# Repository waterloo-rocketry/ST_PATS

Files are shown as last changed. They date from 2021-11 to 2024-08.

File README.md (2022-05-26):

# ST PATS
Stpats is a system that tracks the location of the rocket and tells us where
and which direction to go to find it.

There are two modes of operation: serial and radio. In serial mode, GPS
coordinate is received from USB serial; in radio mode, GPS coordinate is
received from the radio module.

## Calibration
The on-board compass needs to be calibrated when a firmware is flashed or when
using stpats in a new environment. The compass will not work correctly without
calibration. To enter calibration mode, press the left button. The min/max
value of each axis should appear on the top left of the screen. Rotate the
whole device in every direction so the numbers stabilize, the press the left
button again to save the calibration.

## Radio Telemetry
The radio and serial mode can be toggled using the right button. At the time of
writing, the live telemetry is not done yet, so I used an Arduino to send fake
coordinates at 57600 baud to test serial reading and parsing. In theory,
plugging in configured live telemetry breakout should just work. In reality,
who knows.

## Serial Telemetry
As an alternative to radio telemetry, USB serial can also be used to send GPS
coordinate to stpats. The serial mode can be switched to using the right
button. The GPS message has the format of `[0-9]+.[0-9]*[NSEWM]`, for example:
`12.34N56.78W90M` means 12.34 degrees north, 56.78 degrees west, 90m high. The
altitude information is not used in the calculations so it’s optional.

## aprs2stpats.py
`utils/aprs2stpats.py` can be used to send APRS coordinates to stpats. To use,
install aprspy and bitstring using pip, then follow the steps in
[Receiving APRS Packet](https://uwaterloo.atlassian.net/wiki/spaces/ROCKETRY/pages/43003445444)
to setup and run direwolf TNC as a KISS server.

`usage: aprs2stpats.py [-h] [-H HOST] [-p PORT] [-c CALLSIGN] [-o OUTPUT] [--debug]`

The --host and --port options specifies the KISS TNC server to connect to. By
default, they are 127.0.0.1:8001, which connects to a direwolf instance running
on localhost.

The --callsign option filters the message by sender’s callsign, in case there
are multiple APRS beacons on the same frequency. Note the callsign includes
ssid, for example, VE7OIR-1 instead of just VE7OIR. By default, it forwards all
GPS messages.

The --output option specified the output. By default it is stdout. To send the
output to serial, use --output \\.\COM1 (Windows) or --output /dev/ttyACM0
(Linux), change COM1 or ACM0 to the actual serial port stpats is on.

The --debug options prints additional info to stderr.

## Persistent Location
Press the middle button in either mode to save the current tracking location in
flash so a reset doesn’t lose it. Most useful when one wants to unplug stpats
from computer in serial mode, pressing the middle button before disconnecting
allows one to move around without worrying losing track in case of accidental
reset.

Note: similar to calibration data, flashing a firmware wipes the flash and so
the saved data.

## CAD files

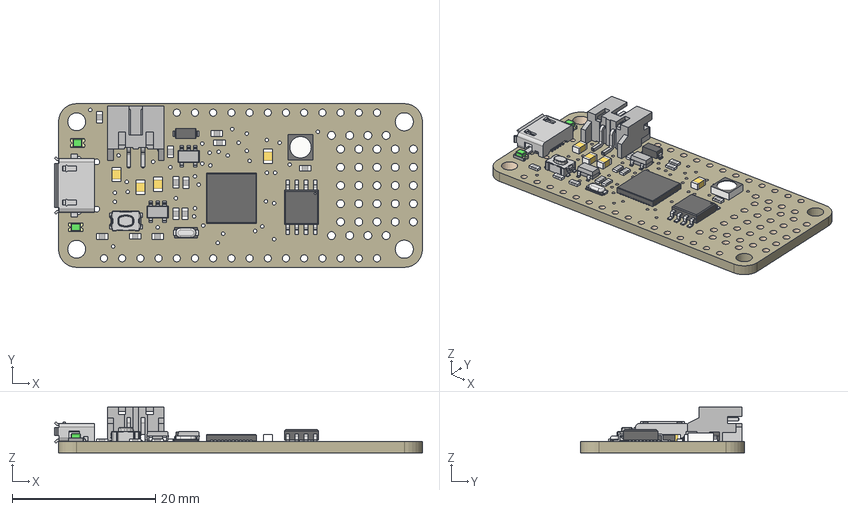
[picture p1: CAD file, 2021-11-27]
schematics/models/3403 Feather M0 Express.step
51.4 x 22.9 x 6.37 mm
Board
10uF x 4
10K x 12
ORANGE x 2
SPST_TACT-KMR2
microUSB
MCP73831T-2ACI/OT x 2
MBR120
JSTPH
ATSAMD21G18_QFN
WS2812B3535
2MB Flash

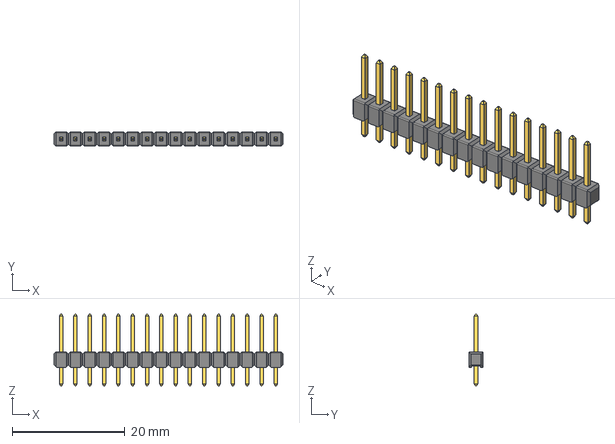
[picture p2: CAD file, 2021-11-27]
schematics/models/Pin Header 1x16 TH Pitch 2.54mm.stp
40.6 x 2.54 x 12.7 mm

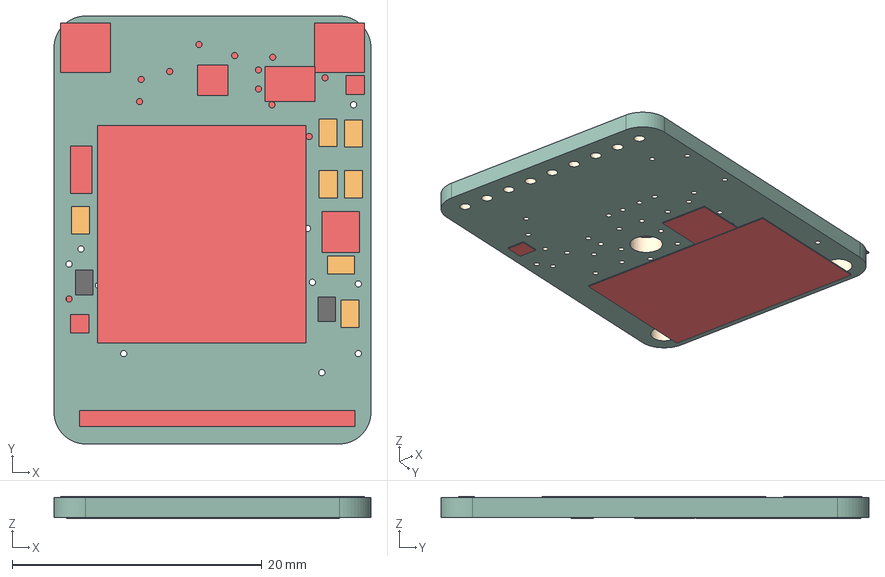
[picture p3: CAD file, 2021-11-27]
schematics/models/Adafruit Ultimate GPS.step
25.4 x 34.3 x 1.77 mm
Board
FGPMMOPA6H
MIC5225-3.3
RED
10K x 7
MOUNTINGHOLE2.5 x 2
CUS520 x 2
CR1220
FIDUCIAL"" x 2
ADAFRUIT_2.5MM
U.FL
1X09_ROUND_70
PCBFEAT-REV-040
ADAFRUIT_5MM

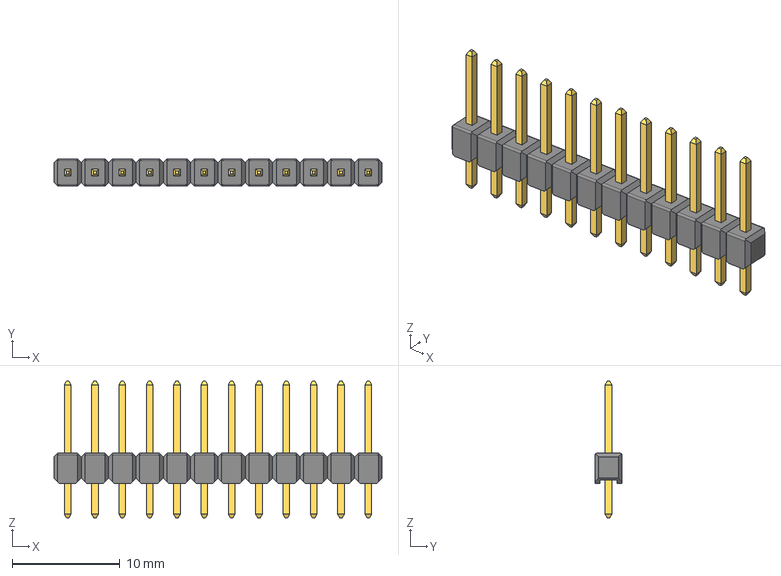
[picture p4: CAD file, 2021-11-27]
schematics/models/Pin Header 1x12 TH Pitch 2.54mm.stp
30.5 x 2.54 x 12.7 mm

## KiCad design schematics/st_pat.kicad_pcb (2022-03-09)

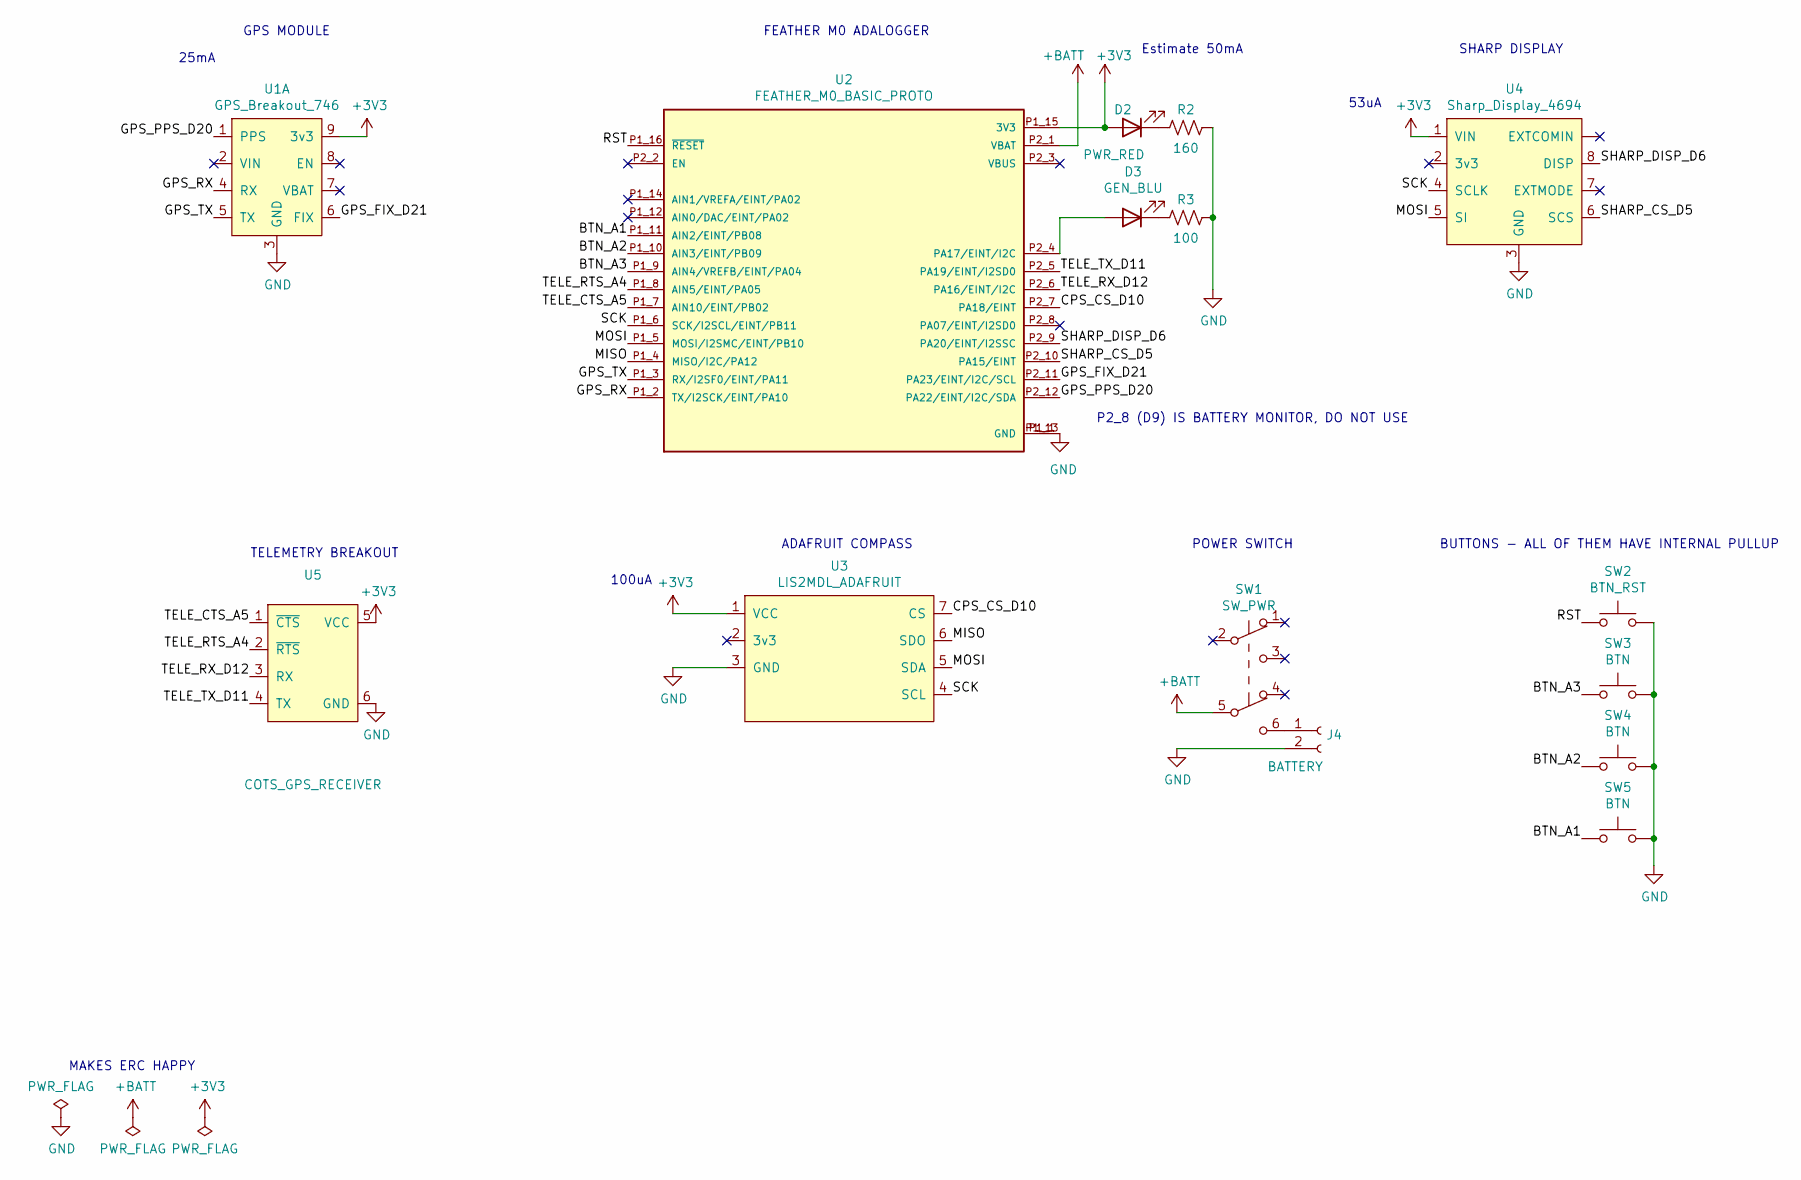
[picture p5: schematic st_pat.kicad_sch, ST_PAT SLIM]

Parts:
D2: PWR_RED; LED_1206_3216Metric_Pad1.42x1.75mm_HandSolder
D3: GEN_BLU; LED_1206_3216Metric_Pad1.42x1.75mm_HandSolder
J4: BATTERY; JST_PH_S2B-PH-K_1x02_P2.00mm_Horizontal
R2: 160; R_0805_2012Metric_Pad1.20x1.40mm_HandSolder
R3: 100; R_0805_2012Metric_Pad1.20x1.40mm_HandSolder
SW1: SW_PWR; SW_Rocker_A22K1H-EA
SW2: BTN_RST; SW_PUSH_6mm
SW3, SW4, SW5: BTN; SW_PUSH_6mm
U1: GPS_Breakout_746
U2: FEATHER_M0_BASIC_PROTO
U3: LIS2MDL_ADAFRUIT; LIS3MDL_ADAFRUIT
U4: Sharp_Display_4694; Sharp_Display
U5: COTS_GPS_RECEIVER; Telemetry_Breakout

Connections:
+3V3: D2.2 (A), U1.9 (3v3), U2.P1_15 (3V3), U3.1 (VCC), U4.1 (VIN), U5.5 (VCC)
+BATT: SW1.5 (B), U2.P2_1 (VBAT)
/BTN_A1: SW5.1, U2.P1_11 (AIN2/EINT/PB08)
/BTN_A2: SW4.1, U2.P1_10 (AIN3/EINT/PB09)
/BTN_A3: SW3.1, U2.P1_9 (AIN4/VREFB/EINT/PA04)
/CPS_CS_D10: U2.P2_7 (PA18/EINT), U3.7 (CS)
/GPS_FIX_D21: U1.6 (FIX), U2.P2_11 (PA23/EINT/I2C/SCL)
/GPS_PPS_D20: U1.1 (PPS), U2.P2_12 (PA22/EINT/I2C/SDA)
/GPS_RX: U1.4 (RX), U2.P1_2 (TX/I2SCK/EINT/PA10)
/GPS_TX: U1.5 (TX), U2.P1_3 (RX/I2SF0/EINT/PA11)
/MISO: U2.P1_4 (MISO/I2C/PA12), U3.6 (SDO)
/MOSI: U2.P1_5 (MOSI/I2SMC/EINT/PB10), U3.5 (SDA), U4.5 (SI)
/RST: SW2.1, U2.P1_16 (~RESET)
/SCK: U2.P1_6 (SCK/I2SCL/EINT/PB11), U3.4 (SCL), U4.4 (SCLK)
/SHARP_CS_D5: U2.P2_10 (PA15/EINT), U4.6 (SCS)
/SHARP_DISP_D6: U2.P2_9 (PA20/EINT/I2SSC), U4.8 (DISP)
/TELE_CTS_A5: U2.P1_7 (AIN10/EINT/PB02), U5.1 (~CTS)
/TELE_RTS_A4: U2.P1_8 (AIN5/EINT/PA05), U5.2 (~RTS)
/TELE_RX_D12: U2.P2_6 (PA16/EINT/I2C), U5.3 (RX)
/TELE_TX_D11: U2.P2_5 (PA19/EINT/I2SD0), U5.4 (TX)
GND: J4.2, R2.2, R3.2, SW2.2, SW3.2, SW4.2, SW5.2, U1.3 (GND), U2.P1_1 (GND), U2.P1_13 (GND), U3.3 (GND), U4.3 (GND), U5.6 (GND)
unnamed: D2.1 (K), R2.1
unnamed: D3.1 (K), R3.1
unnamed: D3.2 (A), U2.P2_4 (PA17/EINT/I2C)
unnamed: J4.1, SW1.6 (C)

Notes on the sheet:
P2_8 (D9) IS BATTERY MONITOR, DO NOT USE
100uA
TELEMETRY BREAKOUT
SHARP DISPLAY
53uA
MAKES ERC HAPPY
BUTTONS - ALL OF THEM HAVE INTERNAL PULLUP
Estimate 50mA
25mA
FEATHER M0 ADALOGGER
POWER SWITCH
ADAFRUIT COMPASS
GPS MODULE

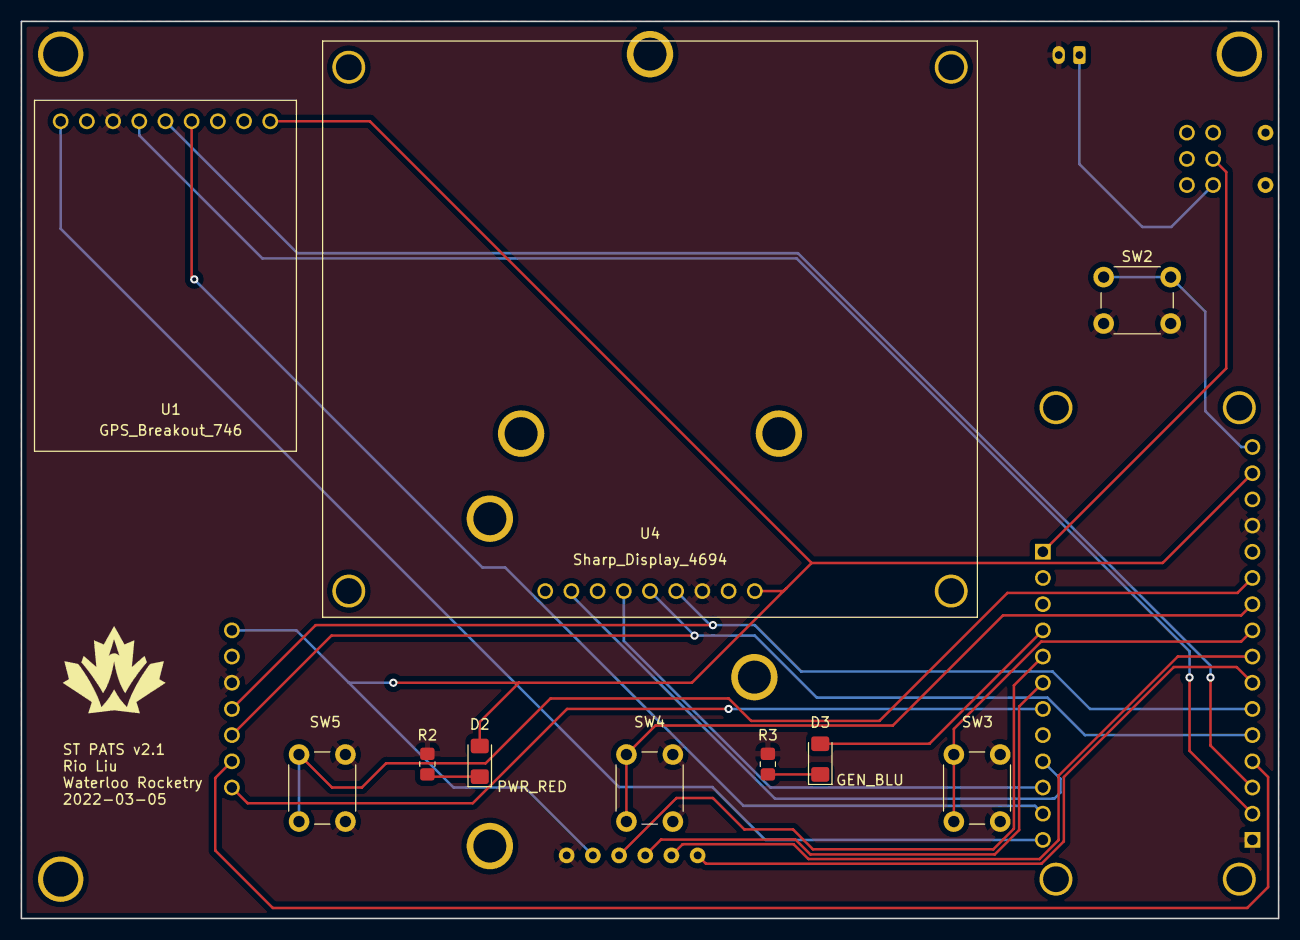
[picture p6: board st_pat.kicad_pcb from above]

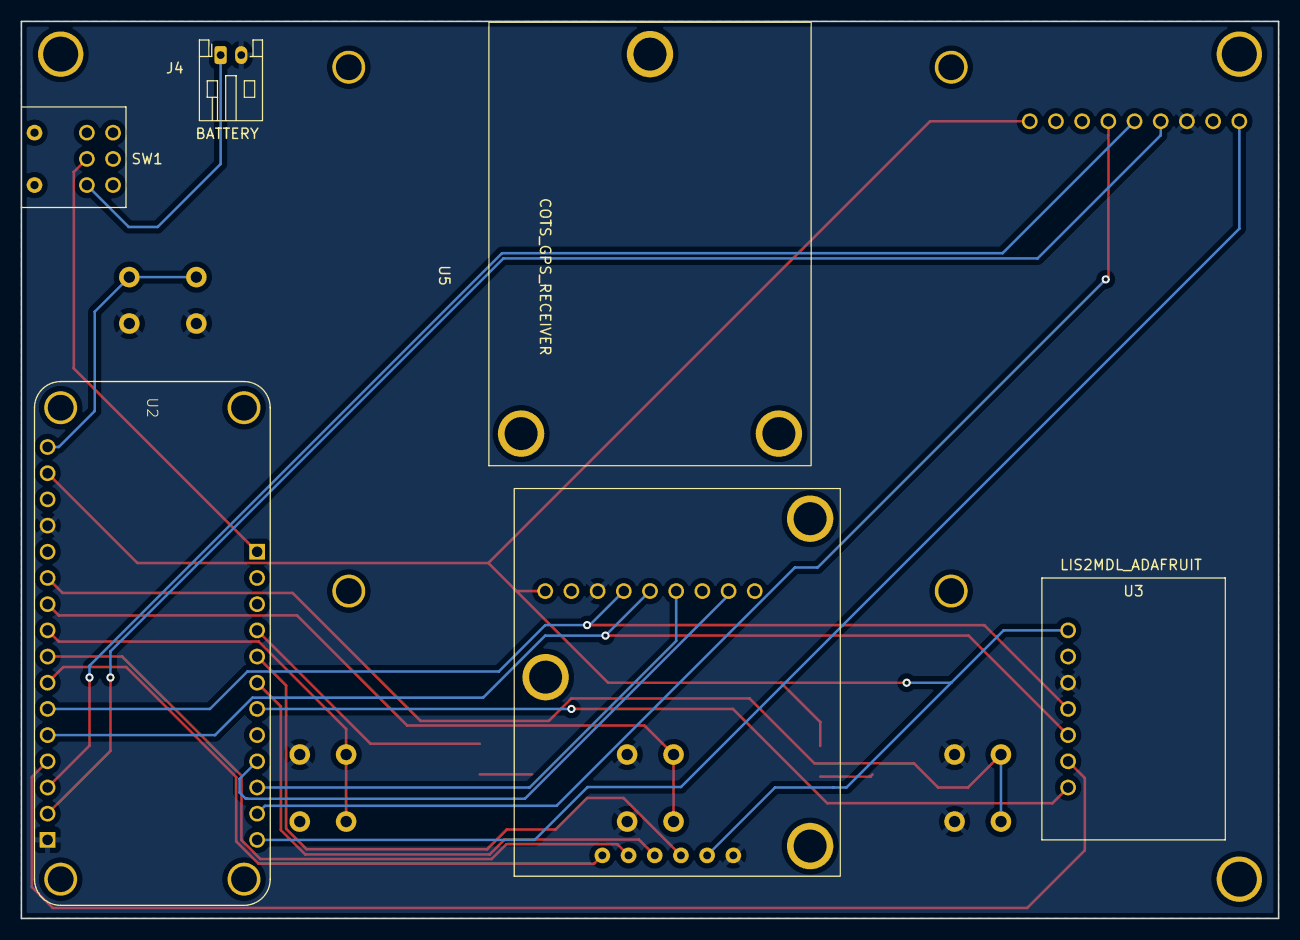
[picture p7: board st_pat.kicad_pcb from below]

Board: 2 copper layers, 121.9 x 87.0 mm, 15 parts (5 on the bottom side), 25 nets.

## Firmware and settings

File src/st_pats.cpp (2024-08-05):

#include <Arduino.h>
#include <Adafruit_SharpMem.h>

#include "compass.h"
#include "gps.h"
#include "display.h"
#include "telemetry.h"

static constexpr int SHARP_SS = 5;
static const int BUTTONS[] = {A1, A2, A3};
static constexpr int BATT = A7;

Adafruit_SharpMem display(SCK, MOSI, SHARP_SS, DISPLAY_W, DISPLAY_H);

#define BEGIN_DEBOUNCE \
do { \
   static long pressed = 0; \
   long now = millis(); \
   if(now - pressed > 500) {
#define END_DEBOUNCE \
   } \
   pressed = now; \
} while(0)

// button 1 toggles compass calibration
static void a1Handler() {
   BEGIN_DEBOUNCE;
   compass_calibrate_toggle();
   END_DEBOUNCE;
}

// button 2 saves current telemetry coordinate to flash
static void a2Handler() {
   BEGIN_DEBOUNCE;
   tele_save(tele_get_mode());
   END_DEBOUNCE;
}

// button 3 toggles telemetry mode
static void a3Handler() {
   BEGIN_DEBOUNCE;
   TeleMode mode = tele_get_mode();
   tele_set_mode(TeleMode((int(mode) + 1) % TELE_MODE_MAX));
   END_DEBOUNCE;
}

static void (*buttonHandlers[])() = {a1Handler, a2Handler, a3Handler};

void setup() {
   // enable float in printf
   asm(".global _printf_float");

   // buttons
   int i = 0;
   for(int button : BUTTONS) {
      pinMode(button, INPUT_PULLUP);
      attachInterrupt(digitalPinToInterrupt(button), buttonHandlers[i++], FALLING);
   }

   // led output
   pinMode(LED, OUTPUT);

   // battery sensing
   pinMode(BATT, INPUT);

   // display
   display.begin();
   display.cp437(true);
   display.setTextSize(2);
   display.setTextColor(0);
   display.setRotation(2);

   // other
   gps_init();
   tele_init();
   compass_init();
}

void loop() {
   display.clearDisplayBuffer();

   gps_update();
   compass_update();
   tele_update();

   // (value + continuity correction) / 10bit ADC * vref * voltage division
   float vbat = (analogRead(BATT) + 0.5) / 1024 * 3.3 * 2;
   display.setCursor(5, DISPLAY_H - 20);
   display.print(vbat);
   display.print("V");

   display.refresh();
}

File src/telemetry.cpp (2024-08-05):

#include <Arduino.h>
#include <wiring_private.h> // pinPeripheral
#include <FlashStorage.h>

#include "telemetry.h"
#include "display.h"
#include "gps.h"
#include "crc8.h"

static constexpr int TELE_TX = 11;
static constexpr int TELE_RX = 12;
static constexpr int TELE_RTS = A4;
static constexpr int TELE_CTS = A5;

static constexpr int BUFF_SIZE = 13;
static constexpr int GPS_LAT_ID = 0x6E0;
static constexpr int GPS_LON_ID = 0x700;
static constexpr int GPS_ALT_ID = 0x720;
static constexpr int GPS_INFO_ID = 0x740;

enum MessageType {
   GPS_LATITUDE = 0x6E0,
   GPS_LONGITUDE = 0x700,
   GPS_ALTITUDE = 0x720,
};

static Uart TeleSerial(&sercom1, TELE_RX, TELE_TX, SERCOM_RX_PAD_3, UART_TX_PAD_0, TELE_RTS, TELE_CTS);

struct Coordinate {
   float lat, lon, alt; // rad, rad, meters
};

static TeleMode mode = TELE_MODE_RADIO;
static Time lastReceived = {0};
static int numSats = 0;
static Coordinate coords[TELE_MODE_MAX];

// macro defining coordStorage*
FlashStorage(coordStorage0, Coordinate);
FlashStorage(coordStorage1, Coordinate);
FlashStorage(coordStorage2, Coordinate);

FlashStorageClass<Coordinate> coordStorages[TELE_MODE_MAX] = {
   coordStorage0, coordStorage1, coordStorage2,
};

static void to_degs(float rad, int &deg, float &min) {
   float degFloat = rad / TWO_PI * 360;
   deg = (int) degFloat;
   min = (degFloat - deg) * 60;
}

void SERCOM1_Handler() {
   TeleSerial.IrqHandler();
}

void tele_init() {
   // Telemetry breakout serial
   TeleSerial.begin(115200);
   TeleSerial.setTimeout(200);
   pinPeripheral(TELE_RX, PIO_SERCOM);
   pinPeripheral(TELE_TX, PIO_SERCOM);

   // USB Serial
   Serial.begin(9600);
   Serial.setTimeout(200);
   
   // Restore saved coordinate
   for(TeleMode m = TELE_MODE_RADIO; m < TELE_MODE_MAX; m = TeleMode(int(m)+1)) {
      tele_load(m);
   }
}

void tele_load(TeleMode mode) {
   coordStorages[mode].read(&coords[mode]);
}

void tele_save(TeleMode mode) {
   switch(mode) {
      case TELE_MODE_HOME:
         if(!gps_fixed()) return;
         gps_coord(coords[mode].lat, coords[mode].lon, coords[mode].alt);
         coordStorages[mode].write(coords[mode]);
         break;
      default:
         coordStorages[mode].write(coords[mode]);
         break;
   }
}

// get gps from radio
static bool tele_recv_radio() {
   static enum {
      WAITING,
      SIZE_SID,
      SID,
      DATA,
      CHECKSUM
   } state = WAITING;

   static struct {
      uint8_t data_len;
      uint16_t sid;
      uint8_t data[8];
      uint8_t checksum;
   } msg = {0};

   // circular buffer for back tracking when header is out of sync
   static uint8_t buff[BUFF_SIZE] = {0};
   static int head = 0, end = 0, now = 0;

   // keep track of these so no need to calculate from head, end, now
   static int count = 0;
   static int size = 0;

   bool received = false;

   // handle telemetry radio
   while(TeleSerial.available()) {
      // write to buffer
      buff[end] = TeleSerial.read();
      end = (end + 1) % sizeof(buff);
      if(end == head) {
         // overflow, malformed message (too large), reset
         state = WAITING;
      }

      // process buffer
      // normally, just the last byte that was read is processed
      // but in case of mismatched checksum, now is rolled back to the next
      // header byte and bytes in buffer is re-parsed.
      while(now != end) {
         uint8_t b = buff[now];
         switch(state) {
            case WAITING:
               if(b == 0x02) { // header byte
                  msg.sid = 0;
                  msg.data_len = 0;
                  msg.checksum = 0;
                  head = now;
                  count = 0;
                  state = SIZE_SID;
               }
               break;

            case SIZE_SID:
               size = b >> 4 & 0x0F;
               msg.data_len = size - 4;
               msg.sid = b << 8 & 0x0700;
               state = SID;
               break;

            case SID:
               msg.sid |= b;
               state = DATA;
               break;

            case DATA:
               msg.data[count-3] = b;
               if(count >= size - 2) {
                  state = CHECKSUM;
               }
               break;

            case CHECKSUM:
               if(msg.checksum != b) {
                  // mismatched checksym
                  // find the next header in buffer and rollback to that position
                  // if no header is found, then now = end and loop exits
                  now = head;
                  do {
                     now = (now + 1) % sizeof(buff);
                  } while(now != end && buff[now] != 0x02);
               } else {
                  // process the parsed message
                  switch(msg.sid & 0xFE0) {
                     case GPS_LAT_ID:
                        if(msg.data_len < 8) break;
                        coords[TELE_MODE_RADIO].lat = (msg.data[3]
                           + (float) msg.data[4] / 60
                           + (float) (msg.data[5] << 8 | msg.data[6]) / 600000) / 360 * TWO_PI;
                        if(msg.data[7] == 'S') coords[TELE_MODE_RADIO].lat = -coords[TELE_MODE_RADIO].lat;
                        received = true;
                        break;

                     case GPS_LON_ID:
                        if(msg.data_len < 8) break;
                        coords[TELE_MODE_RADIO].lon = (msg.data[3]
                           + (float) msg.data[4] / 60
                           + (float) (msg.data[5] << 8 | msg.data[6]) / 600000) / 360 * TWO_PI;
                        if(msg.data[7] == 'W') coords[TELE_MODE_RADIO].lon = -coords[TELE_MODE_RADIO].lon;
                        received = true;
                        break;

                     case GPS_ALT_ID:
                        if(msg.data_len < 5) break;
                        coords[TELE_MODE_RADIO].alt = (msg.data[3] << 8 | msg.data[4]) + (float) msg.data[5] / 100;
                        received = true;
                        break;

                     case GPS_INFO_ID:
                        numSats = msg.data[3];
                        break;
                  }
               }

               state = WAITING;
               continue; // skip the rest of processing
         }

         msg.checksum = crc8_checksum(&b, 1, msg.checksum);
         now = (now + 1) % sizeof(buff);
         count++;
      }
   }

   return received;
}
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

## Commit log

2019-05-21 Added ST_PATS CAD model and currently empty compass calibration program.
2019-06-10 added suport for RocketCAN GPS and code to check button and led functionality
2019-06-13 minimum functionality acheived! still need to finish implementing distance to target, as well as internall compass and battery voltage checking but thease are lower priorities
2019-06-14 commented out arrow as it is currently useless, added magnetic declination compensation, implemented distance function, tentitively fixed BRB parsing bug
2021-01-24 start st-pat-slim hardware
    [st_pat.kicad_pcb, st_pat.sch]
2021-01-30 Switch to use Feather M0 Adalogger board
    [st_pat.sch]
2021-02-06 add compass to schematic
    [st_pat.sch]
2021-02-06 Update schematic - clearer label, add capacitor to GPS
    [st_pat.sch]
2021-02-06 Remove global tags and fix ERC
    [st_pat.sch]
2021-02-07 Add some leds and switches
    [st_pat.sch]
2021-02-14 Update schematic
    [st_pat.sch]
2021-02-14 Found symbol and footprint for adafruit feather
    [st_pat.sch]
2021-02-16 Add one more led to schematic and create pcb
    [st_pat.kicad_pcb, st_pat.sch]
2021-02-16 remove autogenerated files
    [st_pat.kicad_pcb]
2021-02-22 Add missing telemetry breakout board
    [st_pat.kicad_pcb, st_pat.sch]
2021-02-24 Rearrange board layout
    [st_pat.kicad_pcb]
2021-03-03 Redo layout and fix some small schematic issues
    [st_pat.kicad_pcb, st_pat.sch]
2021-03-06 Re add routes
    [st_pat.kicad_pcb]
2021-03-11 fix board outline
    [st_pat.kicad_pcb]
2021-05-08 add sharp display number to schematic
    [st_pat.sch]
2021-05-13 redo board layout
    [st_pat.kicad_pcb]
2021-05-31 add power estimate to each component
    [st_pat.sch]
2021-06-03 fix pr issues
    [st_pat.kicad_pcb, st_pat.sch]
2021-07-05 wip replacing gps module with breakout
    [st_pat.kicad_pcb, st_pat.sch]
2021-07-10 wip: redo layout and use diffrent button footprint
    [st_pat.kicad_pcb, st_pat.sch]
2021-07-18 update buttons layout and redo traces; add 3d model for adafruit feather
    [3403 Feather M0 Express.step, Pin Header 1x12 TH Pitch 2.54mm.stp, Pin Header 1x16 TH Pitch 2.54mm.stp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]
2021-07-28 add gps model to board
    [Adafruit Ultimate GPS.step, st_pat.kicad_pcb]
2021-07-30 increase spacing for leds
    [st_pat.kicad_pcb]
2021-09-30 add waterloo rocketry logo and generate gerber
    [st_pat-B_Cu.gbr, st_pat-B_Mask.gbr, st_pat-B_SilkS.gbr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]
2021-10-03 fix silkscreen position
    [st_pat-B_Cu.gbr, st_pat-B_Mask.gbr, st_pat-B_SilkS.gbr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]
2022-03-04 update schematics for new telemetry breakout board
    [st_pat.kicad_pcb, st_pat.kicad_sch]
2022-03-05 update display and telemetry breakout footprints
    [st_pat.kicad_sch]
2022-03-05 fix sch review issues
    [st_pat.kicad_pcb, st_pat.kicad_sch]
2022-03-05 update telemetry breakout footprint and redo layout and routing
    [st_pat.kicad_pcb]
2022-03-05 remove old kicad files
    [st_pat.sch]
2022-03-06 fix review issues
    [st_pat.kicad_pcb]
2022-03-07 add dimensions to board
    [st_pat.kicad_pcb]
2022-03-07 regenerate gerbers
    [st_pat-B_Cu.gbl, st_pat-B_Cu.gbr, st_pat-B_Mask.gbr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]
2022-03-09 Refill out-of-date zones, regenerate gerbers
    [st_pat-B_Cu.gbl, st_pat-B_Mask.gbs, st_pat-B_Paste.gbp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]
2022-03-17 add persistant calibration data storage
2022-04-03 fix typo in schematic and remove calibration test code
    [st_pat.kicad_sch]
2022-04-04 buttons, and fix sprintf warnings
    [st_pats.cpp, telemetry.cpp]
2022-04-19 make button 2 save current coordinate
2022-04-19 use led to show receive status
2022-05-01 remove dedfault callsign filter
2024-08-04 update telemetry radio to new canbus format
2024-08-04 add battery voltage monitor
2024-08-04 check for message id before sscanf and ignore board id
2024-08-04 fix different tele mode overwriting, fix distance calc
    [telemetry.cpp]
2024-08-04 make st_pats act as serial gps device
